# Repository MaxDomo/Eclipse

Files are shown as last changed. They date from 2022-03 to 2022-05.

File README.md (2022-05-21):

# Projet Eclipse

Bienvenue sur ce projet de motorisation de la lampe IKEA modèle PS2014

Vous pouvez retrouver l'ensemble de ce projet sur cet [article](https://www.domotioque-passion.fr/).

## Circuits et Schémas

Les circuits et schémas ont été conçus avec KiCad 6.0

## Pièces 3D

Les pièces ont été modélisées à l'aide de SolidWorks 2018.

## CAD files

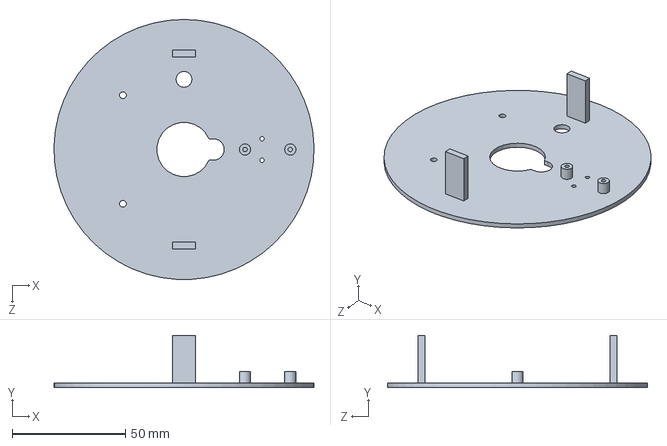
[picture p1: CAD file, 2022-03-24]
Pièces 3D/Support relais transformateur.SLDPRT
114.9 x 23.0 x 115.0 mm

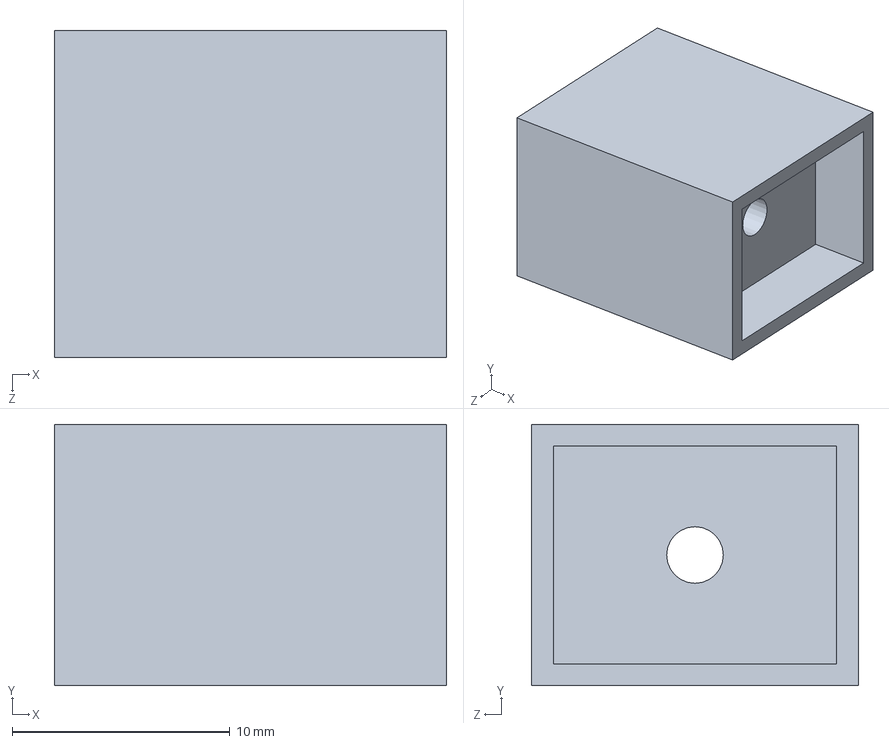
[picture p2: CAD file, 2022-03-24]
Pièces 3D/Support tendeur basV2.SLDPRT
18.0 x 12.0 x 15.0 mm

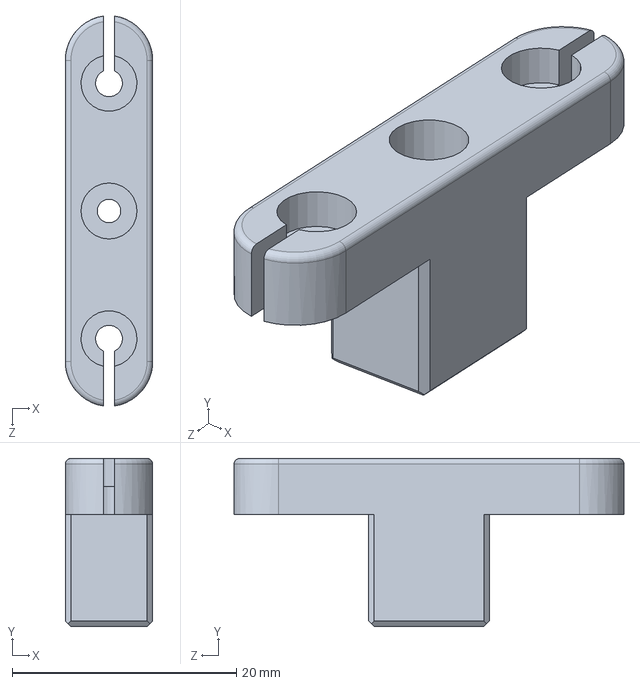
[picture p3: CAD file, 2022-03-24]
Pièces 3D/Tendeur basV2.SLDPRT
7.80 x 15.0 x 34.8 mm

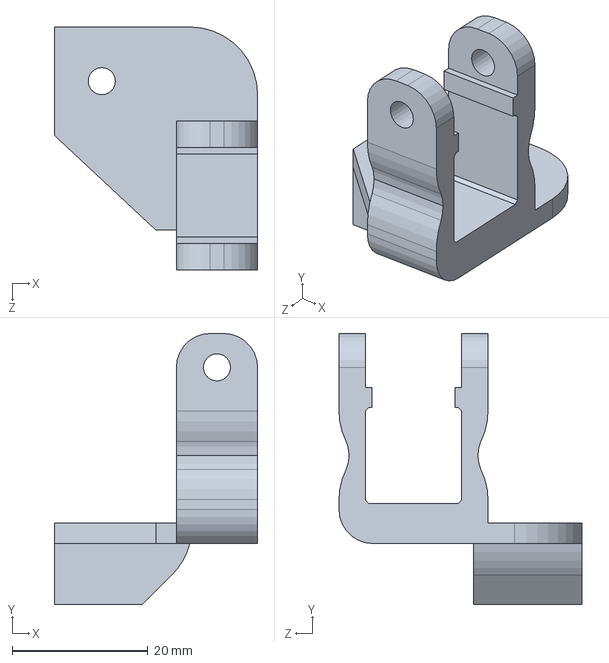
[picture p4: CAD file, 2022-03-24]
Pièces 3D/Support moteur.SLDPRT
30.0 x 40.0 x 35.9 mm

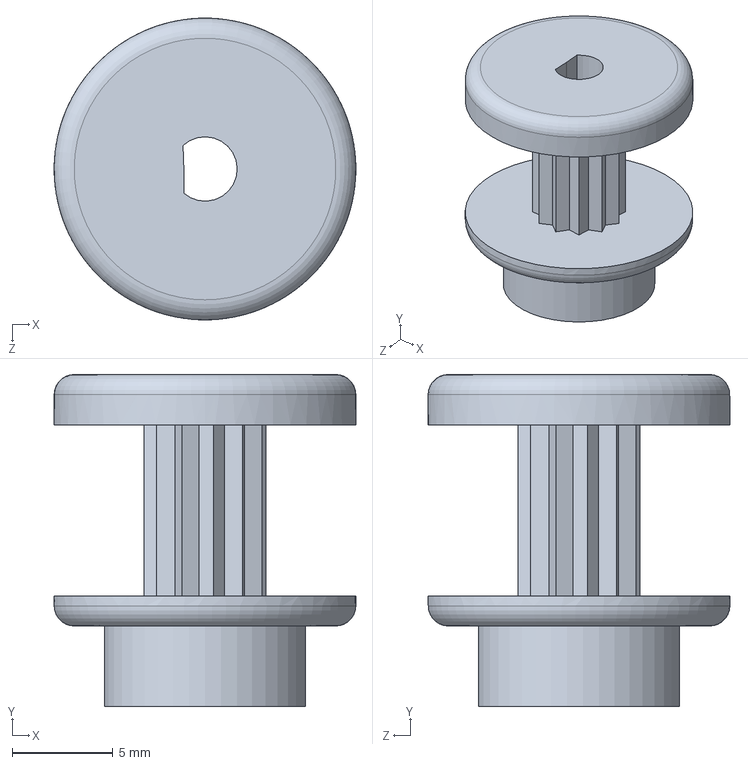
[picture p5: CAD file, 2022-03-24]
Pièces 3D/Roue tractionV2.SLDPRT
15.0 x 16.5 x 15.0 mm

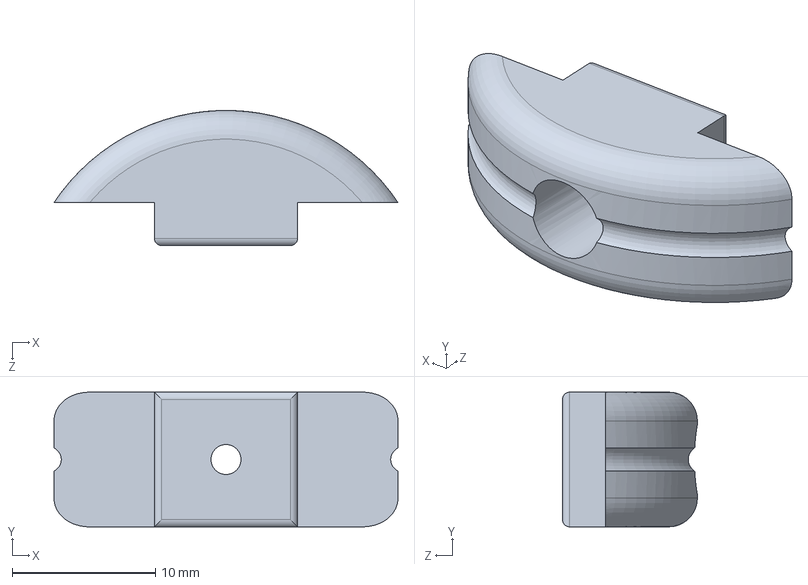
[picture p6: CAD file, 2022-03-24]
Pièces 3D/Tendeur hautV2.SLDPRT
24.0 x 9.40 x 9.42 mm

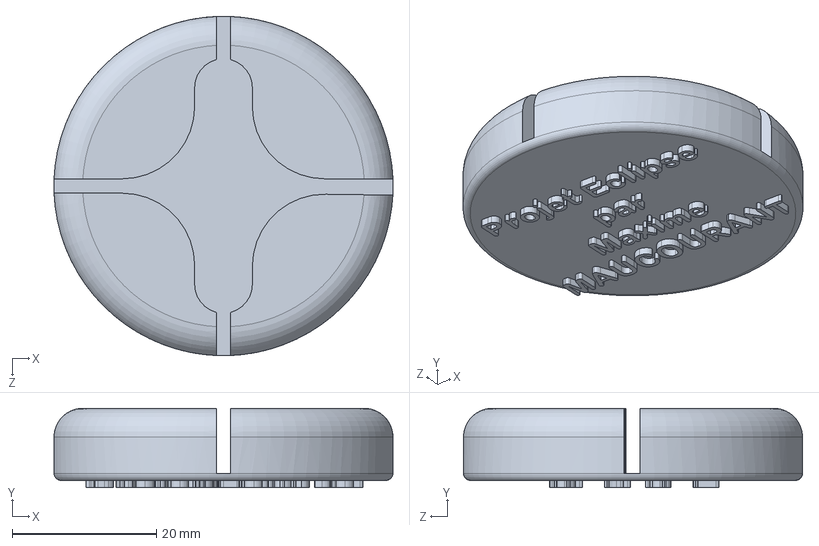
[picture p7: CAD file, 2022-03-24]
Pièces 3D/Estampille.SLDPRT
47.0 x 11.0 x 47.0 mm

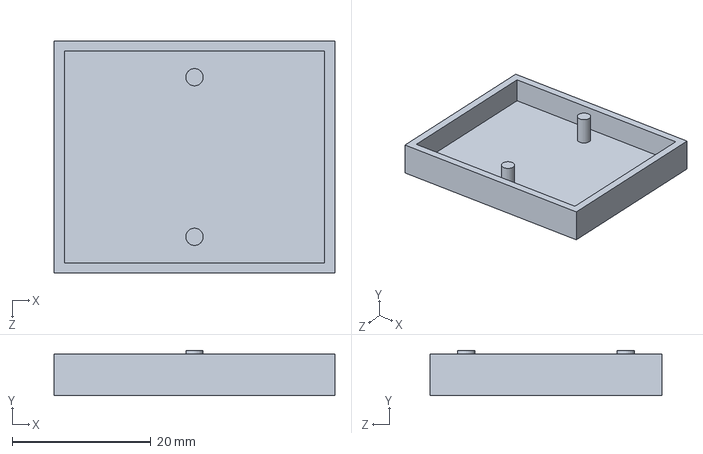
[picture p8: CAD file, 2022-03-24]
Pièces 3D/support carte relais.SLDPRT
40.5 x 6.50 x 33.5 mm

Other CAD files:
Pièces 3D/Roue traction.SLDPRT
Pièces 3D/Estampille.STL
Pièces 3D/Roue traction.STL
Pièces 3D/Roue tractionV2.STL
Pièces 3D/Support moteur.STL
Pièces 3D/Support relais transformateur.STL
Pièces 3D/Support tendeur basV2.STL
Pièces 3D/Tendeur basV2.STL
Pièces 3D/Tendeur hautV2.STL
Pièces 3D/support carte relais.STL

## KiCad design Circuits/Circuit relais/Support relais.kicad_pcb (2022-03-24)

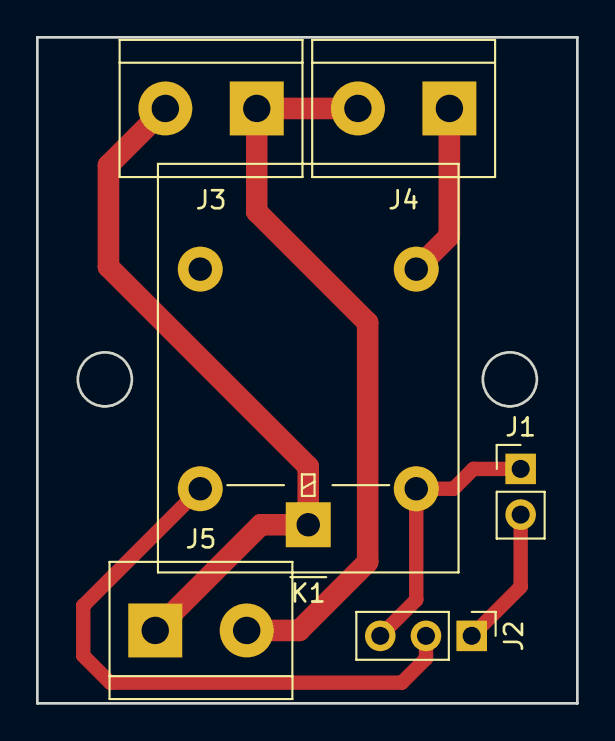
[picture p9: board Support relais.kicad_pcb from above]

Board: 2 copper layers, 30.0 x 37.0 mm, 6 parts (0 on the bottom side), 6 nets.

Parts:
J1: Conn_Power; PinHeader_1x02_P2.54mm_Vertical
J2: Conn_Power&Control; PinHeader_1x03_P2.54mm_Vertical
J3: AC Input; TerminalBlock_bornier-2_P5.08mm
J4: Light; TerminalBlock_bornier-2_P5.08mm
J5: Transformer; TerminalBlock_bornier-2_P5.08mm
K1: 5V; Relay_SPDT_Omron-G5LE-1

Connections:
unnamed: J1.1, J2.3, K1.2
unnamed: J1.2, J2.1
unnamed: J2.2, K1.5
unnamed: J4.1, K1.3
unnamed: J3.1, J4.2, J5.2
unnamed: J3.2, J5.1, K1.1

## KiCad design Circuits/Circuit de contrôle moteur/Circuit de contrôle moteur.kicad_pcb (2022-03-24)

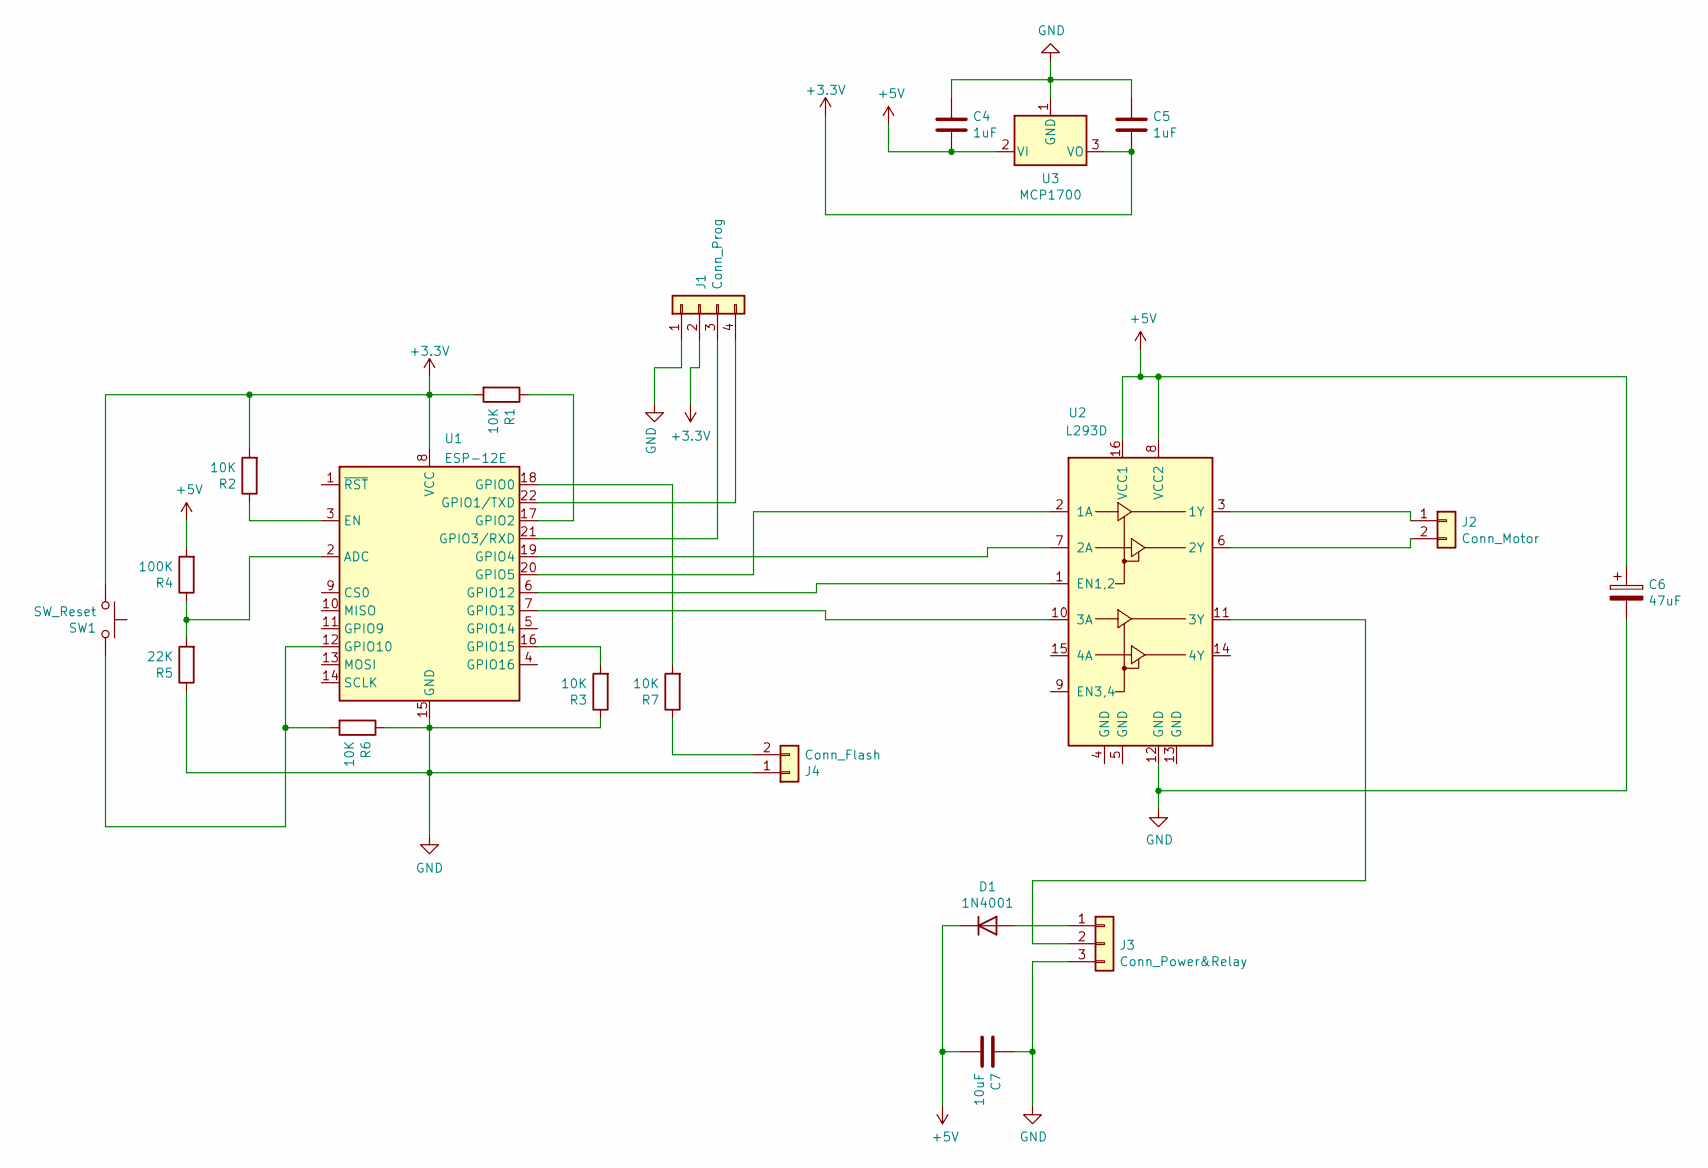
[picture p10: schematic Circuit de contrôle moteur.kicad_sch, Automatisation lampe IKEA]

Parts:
C4, C5: 1uF; C_Rect_L4.0mm_W2.5mm_P2.50mm
C6: 47uF; CP_Radial_D5.0mm_P2.50mm
C7: 10uF; C_Rect_L4.0mm_W2.5mm_P2.50mm
D1: 1N4001; D_DO-35_SOD27_P7.62mm_Horizontal
J1: Conn_Prog; PinHeader_1x04_P2.54mm_Vertical
J2: Conn_Motor; PinHeader_1x02_P2.54mm_Vertical
J3: Conn_Power&Relay; PinHeader_1x03_P2.54mm_Vertical
J4: Conn_Flash; PinHeader_1x02_P2.54mm_Vertical
R1, R2, R3, R6, R7: 10K; R_Axial_DIN0204_L3.6mm_D1.6mm_P7.62mm_Horizontal
R4: 100K; R_Axial_DIN0204_L3.6mm_D1.6mm_P7.62mm_Horizontal
R5: 22K; R_Axial_DIN0204_L3.6mm_D1.6mm_P7.62mm_Horizontal
SW1: SW_Reset; SW_PUSH_6mm_H4.3mm
U1: ESP-12E
U2: L293D; DIP-16_W7.62mm
U3: MCP1700; TO-92L_Wide

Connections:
+3V3: C5.2, J1.2, R1.2, R2.2, SW1.1, U1.8 (VCC), U3.3 (VO)
+5V: C4.2, C6.1, C7.2, D1.1 (K), R4.2, U2.8 (VCC2), U2.16 (VCC1), U3.2 (VI)
GND: C4.1, C5.1, C6.2, C7.1, J1.1, J3.3, J4.1, R3.1, R5.1, R6.1, U1.15 (GND), U2.12 (GND), U3.1 (GND)
unnamed: D1.2 (A), J3.1
unnamed: J1.3, U1.21 (GPIO3/RXD)
unnamed: J1.4, U1.22 (GPIO1/TXD)
unnamed: J2.1, U2.3 (1Y)
unnamed: J2.2, U2.6 (2Y)
unnamed: J3.2, U2.11 (3Y)
unnamed: J4.2, R7.1
unnamed: R1.1, U1.17 (GPIO2)
unnamed: R2.1, U1.3 (EN)
unnamed: R3.2, U1.16 (GPIO15)
unnamed: R4.1, R5.2, U1.2 (ADC)
unnamed: R7.2, U1.18 (GPIO0)
unnamed: U1.6 (GPIO12), U2.1 (EN1,2)
unnamed: U1.7 (GPIO13), U2.10 (3A)
unnamed: R6.2, SW1.2, U1.12 (GPIO10)
unnamed: U1.19 (GPIO4), U2.7 (2A)
unnamed: U1.20 (GPIO5), U2.2 (1A)

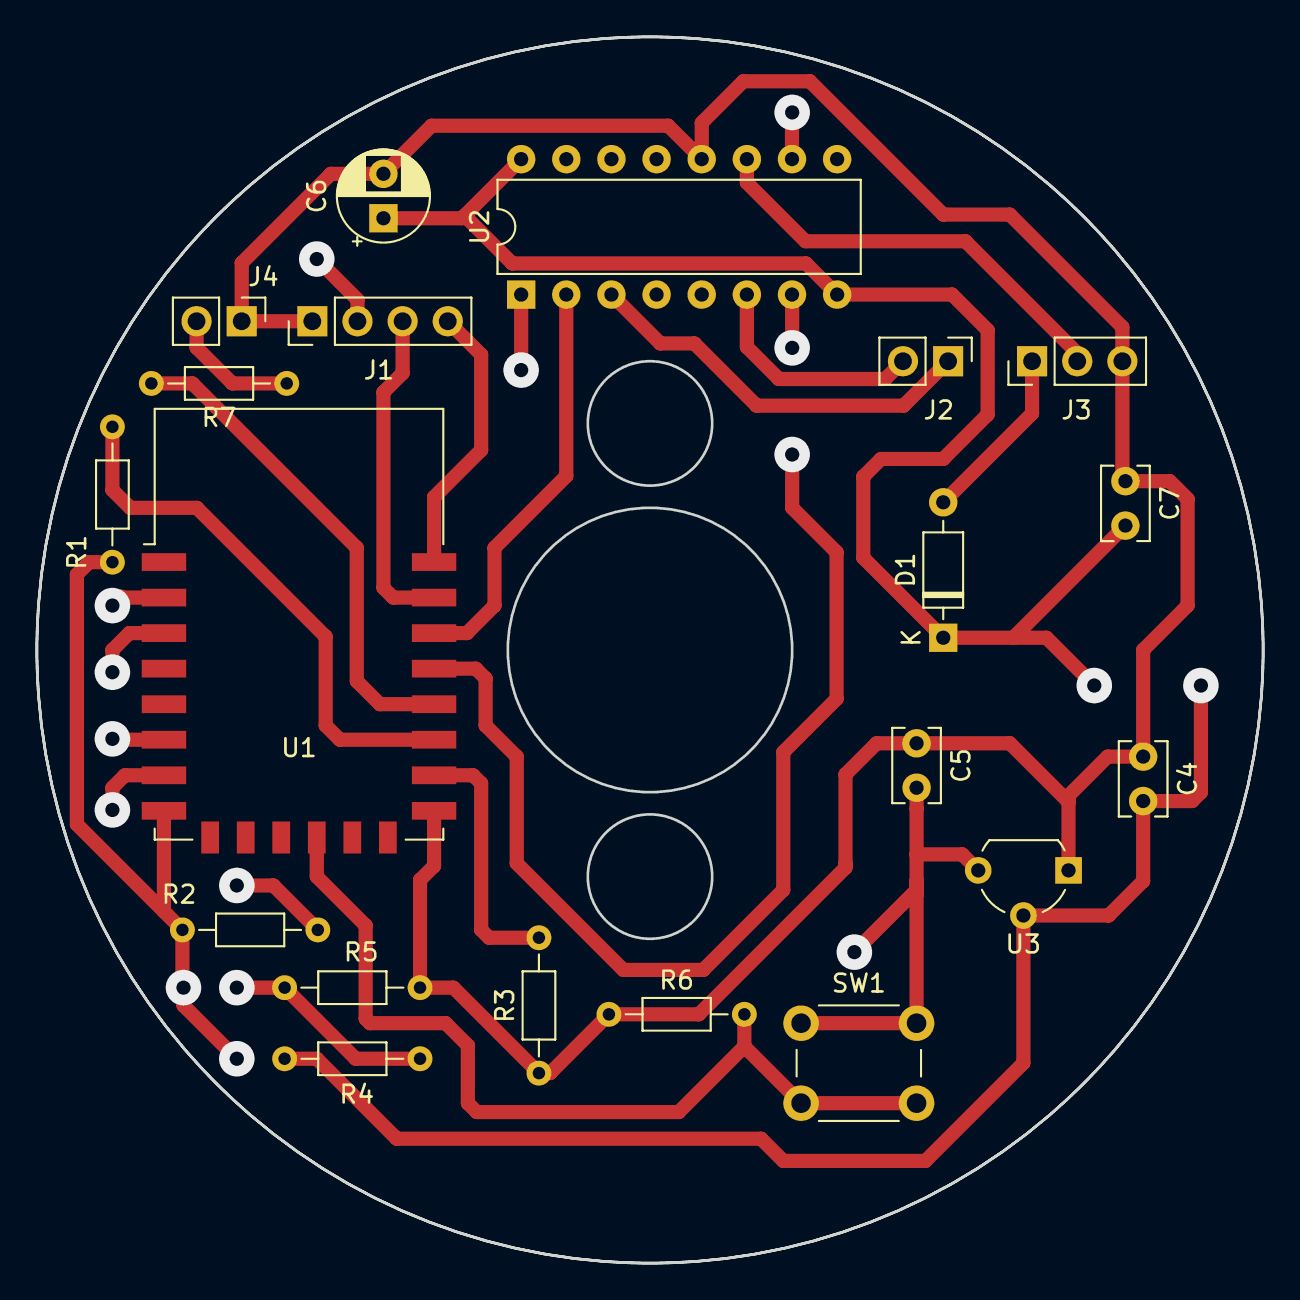
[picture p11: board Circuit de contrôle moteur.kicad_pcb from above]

Board: 2 copper layers, 69.0 x 69.0 mm, 20 parts (0 on the bottom side), 20 nets.

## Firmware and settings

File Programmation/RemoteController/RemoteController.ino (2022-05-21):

/////////////////////////////////
//       Projet ECLIPSE        //
// Ecrit par Maxime MAUCOURANT //
// MMAUCOURANT AT FREE DOT FR  //
/////////////////////////////////
#include <ESP8266WiFi.h>
#include <ESP8266HTTPClient.h>
#include <ESP8266WebServer.h>
#include <ESP8266mDNS.h>
#include "ESP8266httpUpdate.h"
#include <ArduinoJson.h>
#include <LittleFS.h>
#include "PubSubClient.h"
#include "EspAlexa.h"
#include "strings.h"

#define USEOTA
#ifdef USEOTA
#include <WiFiUdp.h>
#include <ArduinoOTA.h>
#endif

#define HTTP_OTA_URL "http://firmwares.domotique-passion.fr/eclipse/"
#define FIRMWARE_NAME "eclipse-v1.70-BETA"

#define FPSTR(pstr_pointer) (reinterpret_cast<const __FlashStringHelper *>(pstr_pointer))

#define pinSpeed 12
#define pinA 5
#define pinB 4

#define pinRelay 13 // Revoir l'affectation de la pin

#define pinSwitch 10

void lightDeviceChanged(EspalexaDevice *dev);
void lampShadeDeviceChanged(EspalexaDevice *dev);

// Déclaration du client Wifi
WiFiClient wifiClient;

// Déclaration du serveur web
ESP8266WebServer server(80);

// Déclaration du client MQTT
PubSubClient mqttClient(wifiClient);

DynamicJsonDocument config(1024);

Espalexa espalexa;
EspalexaDevice *lightDevice;
EspalexaDevice *lampShadeDevice;

int delayedPeriod = 1000;
unsigned long delayedTime;
void (*delayedFunction)();

// Init délai de tempo moteur
long motionDuration = 0;

// Init vitesse moteur
int motorSpeed = 100;

bool isRunning = false;
bool isClosed = false;

// Init délais d'ouverture/fermeture
int openingTime;
int closingTime;

// Init actions du moteur
int motorAction = -1;

// Init restauration états après coupure
bool restoreLastState = false;

// Variable pour la connexion à un nouveau réseau wifi
String newSSID;
String newPass;

// Etat de la dernière mise à jour
String lastUpdateStatus;

const char *hueLightName = "Eclipse light";
const char *hueLampshadeName = "Eclipse lampshade";

int mqttReconnectTime = 0;

int motorMotionTime = 0;

// Etat de la lumière
String lightStatus;

// Etat de l'abat jour
String lampshadeStatus;

int statusTime;

bool lastWifiConnected = false;

// Paramètre IP de station
IPAddress localIP(192, 168, 1, 1);
IPAddress gateway(192, 168, 1, 249);
IPAddress subnet(255, 255, 255, 0);

bool hueEnabled = false;
bool mqttEnabled = false;

void restart()
{
  if (WiFi.isConnected())
  {
    WiFi.disconnect();

    delay(1000);
  }

  ESP.restart();
}

IPAddress str2IP(String str)
{

  IPAddress ret(getIpBlock(0, str), getIpBlock(1, str), getIpBlock(2, str), getIpBlock(3, str));
  return ret;
}

int getIpBlock(int index, String str)
{
  char separator = '.';
  int found = 0;
  int strIndex[] = {0, -1};
  int maxIndex = str.length() - 1;

  for (int i = 0; i <= maxIndex && found <= index; i++)
  {
    if (str.charAt(i) == separator || i == maxIndex)
    {
      found++;
      strIndex[0] = strIndex[1] + 1;
      strIndex[1] = (i == maxIndex) ? i + 1 : i;
    }
  }

  return found > index ? str.substring(strIndex[0], strIndex[1]).toInt() : 0;
}

String JSONStringify(DynamicJsonDocument json)
{
  String buf;
  serializeJson(json, buf);
  return buf;
}

String getHostname()
{
  String macAddr = WiFi.macAddress();
  macAddr = macAddr.substring(10, macAddr.length());
  macAddr.replace(":", "");

  String hostname = "eclipse";
  hostname += "-";
  hostname += macAddr;

  return hostname;
}

// Fonction permettant d'obtenir la tension en milliVolt dans le circuit
unsigned int getVcc()
{
  // Calcul ADC
  // R1 = 100K
  // R2 = 22K
  // Vout = Vin * R2 / (R1 + R2)
  // 5 * 22 / (100 + 22) = 0.9016393443
  // Ratio pont diviseur = 5 / 0.9016393443 = 5.54
  // LSB = (0.901639 / 1017) * 5.54 = 0.004911583

  float LSB = 0.004911583;
  int ADC = analogRead(A0);

  return (ADC * LSB) * 1000; // mV
}

void lightBlink(int count = 1, int wait = 500)
{
  // Eteint la lumière
  digitalWrite(pinRelay, LOW);

  // On fait clignoter 3 fois la lumière
  for (int i = 0; i < count; i++)
  {
    delay(wait);
    digitalWrite(pinRelay, HIGH);
    delay(wait);
    digitalWrite(pinRelay, LOW);
  }
}

// Fonction pour construire le topic MQTT
String mqttTopicBuilder(String prefix, String topic)
{
  String fullTopic = config["mqtt"]["full_topic"].as<String>();
  fullTopic.replace("{prefix}", prefix);
  fullTopic.replace("{topic}", config["mqtt"]["topic"].as<String>());
  fullTopic += "/" + topic;

  return fullTopic;
}

// Fonction permettant de publier des messages sur un topic MQTT
void mqttPublish(String prefix, String topic, String payload, bool retain = false)
{
  String fullTopic = mqttTopicBuilder(prefix, topic);

  mqttClient.publish(fullTopic.c_str(), payload.c_str(), retain);
}

// Fonction de connexion au serveur MQTT
void mqttConnect(String client, String user, String pass, String inTopic)
{
  if (pass == "")
  {
    mqttClient.connect(client.c_str());
  }
  else
  {
    mqttClient.connect(client.c_str(), user.c_str(), pass.c_str());
  }

  // Construction des topic lampe et abat jour
  String lightTopic = mqttTopicBuilder("cmnd", "LIGHT");
  String lampshadeTopic = mqttTopicBuilder("cmnd", "LAMPSHADE");

  // Souscription aux topics pour les receptions de messages
  mqttClient.subscribe(lightTopic.c_str());
  mqttClient.subscribe(lampshadeTopic.c_str());
}

void mqttCallback(char *topic, byte *payload, unsigned int length)
{
  String topicStr = topic;
  payload[length] = 0;
  String cmd = String((char *)payload);

  cmd.toLowerCase();

  if (topicStr == mqttTopicBuilder("cmnd", "LIGHT") || topicStr == mqttTopicBuilder("cmnd", "LAMPSHADE"))
  {
    sendCommand(cmd);
  }
}

#ifdef USEOTA
// Fonction permettant d'activer les mises à jour à travers le WiFi (OTA - Over The Air)
void beginOTA(const char *hostname)
{
  ArduinoOTA.setHostname(hostname);
  ArduinoOTA.begin();
}
#endif

// Fonction de chargement du fichier de configuration JSON
void loadConfig()
{
  if (LittleFS.begin())
  {
    if (LittleFS.exists("/config.json"))
    {
      File configFile = LittleFS.open("/config.json", "r");
      if (configFile)
      {
        deserializeJson(config, configFile);

        configFile.close();
      }
    }
  }
}

// Fonction de sauvegarde de configuration dans un fichier JSON
void saveConfig()
{
  File configFile = LittleFS.open("/config.json", "w");
  if (configFile)
  {
    serializeJson(config, configFile);

    configFile.close();
  }
}

// Fonction de réinitialisation de l'ESP
void reset()
{
  if (LittleFS.exists("/config.json"))
  {
    LittleFS.remove("/config.json");
  }

  WiFi.disconnect();
  startSoftAP(getHostname());
  config.clear();
}

// Fonction appelée en cas de page non trouvée (404)
void handleNotFound()
{
  if (hueEnabled && espalexa.handleAlexaApiCall(server.uri(), server.arg(0)))
  {
  }
  else
  {
    server.send(404, "text/plain", "Not found");
  }
}

// Fonction appelée pour le chargement d'un script
void handleJSLib()
{
  server.send(200, "text/plain", FPSTR(JS_lib));
}

// Fonction pour générer la page de config système
void handleConfig()
{
  String page;

  // Construction des éléments du DOM
  page += FPSTR(HTTP_HEAD_START);
  page += FPSTR(HTTP_STYLE);
  page += FPSTR(HTTP_SCRIPT);
  page += FPSTR(HTTP_HEAD_END);
  page += FPSTR(CONFIG_PAGE);
  page += FPSTR(HTTP_END);

  page.replace("{title}", "Configuration");

  server.send(200, "text/html", page);
}

// Fonction pour générer la page principal
void handleRoot()
{
  String page;

  // Construction des éléments du DOM
  page += FPSTR(HTTP_HEAD_START);
  page.replace("{title}", "Main");
  page += "<script src='script.js'></script>";
  page += FPSTR(HTTP_STYLE);
  page += FPSTR(HTTP_HEAD_END);
  page += FPSTR(MAIN_PAGE);
  page += FPSTR(HTTP_END);

  server.send(200, "text/html", page);
}

// Fonction permettant de générer la page de mise à jour du firmware
void handleUpdate()
{
  String page;

  // Construction des éléments du DOM
  page += FPSTR(HTTP_HEAD_START);
  page += FPSTR(HTTP_REFRESH);
  page += FPSTR(HTTP_STYLE);
  page += FPSTR(HTTP_HEAD_END);

  page.replace("{title}", "Firmware Update");

  if (!server.hasArg("finished"))
  {
    page += FPSTR(HTTP_UPDATE_START);

    page.replace("{time}", "30");
    page.replace("{url}", "/update?finished");

    // Lancement de la méthode de vérification d'une mise à jour en mode asynchrone
    delayedPeriod = 2000;
    delayedTime = millis();
    delayedFunction = &checkOTAUpdate;
  }
  else
  {
    page += FPSTR(HTTP_UPDATE_RESULT);

    if (lastUpdateStatus == "")
    {
      lastUpdateStatus = "Update successful";
    }

    page.replace("{updateStatus}", lastUpdateStatus);
    page.replace("{time}", "10");
    page.replace("{url}", "/");
  }

  page += FPSTR(HTTP_END);

  server.send(200, "text/html", page);
}

// Fonction permettant de générer la page de config système
void handleSystem()
{
  String page;

  // Construction des éléments du DOM
  page += FPSTR(HTTP_HEAD_START);
  page += FPSTR(HTTP_STYLE);
  page += FPSTR(HTTP_SCRIPT);
  page += FPSTR(HTTP_HEAD_END);
  page += FPSTR(SYSTEM_PAGE);
  page += FPSTR(HTTP_END);

  // Remplacement des valeurs
  page.replace("{title}", "System Configuration");
  page.replace("{opentime}", (String)(config["open_time"].as<int>() | 0));
  page.replace("{closetime}", (String)(config["close_time"].as<int>() | 0));
  page.replace("{currentvoltage}", (String)getVcc());
  page.replace("{maxdropvoltage}", (String)(config["maxdropvoltage"].as<int>() | 150));
  page.replace("{maxdetectiontime}", (String)(config["maxdetectiontime"].as<int>() | 30));
  page.replace("{synclight}", (config["sync_light"] ? "checked" : ""));

  server.send(200, "text/html", page);
}

// Fonction appelée lors de la sauvegarde de la config système
void handleSystemSave()
{
  String page;

  // Construction des éléments du DOM
  page += FPSTR(HTTP_HEAD_START);
  page += FPSTR(HTTP_REFRESH);
  page += FPSTR(HTTP_STYLE);
  page += FPSTR(HTTP_HEAD_END);

  page.replace("{title}", "System Configuration");

  // Récupération des paramètres POST
  bool syncLight = server.hasArg("synclight");
  int openTime = server.arg("opentime").toInt();
  int closeTime = server.arg("closetime").toInt();
  int maxDropVoltage = server.arg("maxdropvoltage").toInt();
  int maxDetectionTime = server.arg("maxdetectiontime").toInt();

  if (openTime <= 0 || openTime > 30)
  {
    page += FPSTR("Closing time must be between 0 and 30 seconds");
  }
  else if (closeTime <= 0 || closeTime > 30)
  {
    page += FPSTR("Opening time must between 0 and 30 secondes");
  }
  else if (maxDropVoltage <= 0 || maxDropVoltage > 600)
  {
    page += FPSTR("Maximum drop voltage must between 0 and 600 secondes");
  }
  else if (maxDetectionTime <= 0 || maxDetectionTime > 50)
  {
    page += FPSTR("Maximum detection time must between 0 and 50 secondes");
  }
  else
  {
    page += FPSTR(HTTP_SYSTEM_SUCCESS);

    // Sauvegarde des paramètres
    config["sync_light"] = syncLight;
    config["open_time"] = openTime;
    config["close_time"] = closeTime;
    config["max_drop_voltage"] = maxDropVoltage;
    config["max_detection_time"] = maxDetectionTime;

    openingTime = openTime;
    closingTime = closeTime;

    saveConfig();
  }

  page += FPSTR(HTTP_END);

  page.replace("{time}", "5");
  page.replace("{url}", "/system");

  server.send(200, "text/html", page);
}

// Fonction permettant de générer la page de configuration MQTT
void handleMQTT()
{
  String page;

  // Récupération de nom d'hôte
  String hostname = getHostname();

  hostname.replace('-', '_');
  hostname.toUpperCase();

  // Construction des éléments du DOM
  page += FPSTR(HTTP_HEAD_START);
  page += FPSTR(HTTP_STYLE);
  page += FPSTR(HTTP_HEAD_END);
  page += FPSTR(MQTT_PAGE);
  page += FPSTR(HTTP_END);

  // Remplacement des valeurs avec des présentes la configuration
  page.replace("{title}", "MQTT Configuration");
  page.replace("{checked}", (config["mqtt"]["enabled"] ? "checked" : ""));
  page.replace("{host}", config["mqtt"]["host"] | "");
  page.replace("{port}", config["mqtt"]["port"] | "1883");
  page.replace("{port}", config["mqtt"]["port"] | "1883");
  page.replace("{client}", config["mqtt"]["client"] | "eclipse");
  page.replace("{user}", config["mqtt"]["user"] | "");
  page.replace("{pass}", config["mqtt"]["pass"] | "");
  page.replace("{topic}", config["mqtt"]["topic"] | hostname);
  page.replace("{fulltopic}", config["mqtt"]["full_topic"] | "{prefix}/{topic}");

  server.send(200, "text/html", page);
}

// Fontion appelée lors de la sauvegarde de la page de config MQTT
void handleMQTTSave()
{
  String page;

  // Construction des éléments du DOM
  page += FPSTR(HTTP_HEAD_START);
  page.replace("{title}", "MQTT Configuration saved");
  page += FPSTR(HTTP_REFRESH);
  page += FPSTR(HTTP_STYLE);
  page += FPSTR(HTTP_HEAD_END);

  // Récupération des paramètres (POST)
  mqttEnabled = server.hasArg("enable");

  String host = server.arg("host");
  String port = server.arg("port");
  String clientName = server.arg("client");
  String user = server.arg("user");
  String pass = server.arg("pass");
  String topic = server.arg("topic");
  String fullTopic = server.arg("fulltopic");

  if (mqttEnabled && (host == "" || port == ""))
  {
    page += FPSTR("MQTT host or port cannot be empty");
    page.replace("{time}", "5");
  }
  else if (mqttEnabled && user == "")
  {
    page += FPSTR("MQTT user cannot be empty");
    page.replace("{time}", "5");
  }
  else if (mqttEnabled && (topic == "" || fullTopic == ""))
  {
    page += FPSTR("MQTT topic or fullTopic cannot be empty");
    page.replace("{time}", "5");
  }
  else
  {
    page += FPSTR(HTTP_MQTT_SUCCESS);

    // Sauvegarde des paramètres
    config["mqtt"]["enabled"] = mqttEnabled;
    config["mqtt"]["host"] = host;
    config["mqtt"]["port"] = port;
    config["mqtt"]["client"] = clientName;
    config["mqtt"]["user"] = user;
    config["mqtt"]["pass"] = pass;
    config["mqtt"]["topic"] = topic;
    config["mqtt"]["full_topic"] = fullTopic;

    saveConfig();

    page.replace("{time}", "30");

    // Rédemarrage de l'ESP
    delayedPeriod = 5000;
    delayedTime = millis();
    delayedFunction = &restart;
  }

  page += FPSTR(HTTP_END);

  page.replace("{url}", "/mqtt");

  server.send(200, "text/html", page);
}

// Fontion appelée pour construire la page de configuration HUE
void handleHUE()
{
  String page;

  // Construction des éléments du DOM
  page += FPSTR(HTTP_HEAD_START);
  page += FPSTR(HTTP_STYLE);
  page += FPSTR(HTTP_HEAD_END);
  page += FPSTR(HUE_PAGE);
  page += FPSTR(HTTP_END);

  // Remplacement des valeurs
  page.replace("{title}", "HUE Emulator Configuration");
  page.replace("{checked}", (config["hue"]["enabled"] ? "checked" : ""));
  page.replace("{lightname}", config["hue"]["light_name"] | hueLightName);
  page.replace("{lampshadename}", config["hue"]["lampshade_name"] | hueLampshadeName);

  server.send(200, "text/html", page);
}

// Fontion appelée lors de la sauvegarde des paramètres HUE
void handleHUESave()
{
  String page;

  // Construction des éléments du DOM
  page += FPSTR(HTTP_HEAD_START);
  page += FPSTR(HTTP_REFRESH);
  page += FPSTR(HTTP_STYLE);
  page += FPSTR(HTTP_HEAD_END);

  page.replace("{title}", "HUE Emulation Configuration saved");

  hueEnabled = server.hasArg("enable");

  String lightName = server.arg("light-name");
  String lampshadeName = server.arg("lampshade-name");

  if (hueEnabled && (lightName == "" || lampshadeName == ""))
  {
    page += FPSTR("Light or lampshade name cannot be empty !");
    page.replace("{time}", "5");
  }
  else
  {
    page += FPSTR(HTTP_HUE_SUCCESS);

    // Sauvegarde des paramètres
    config["hue"]["enabled"] = hueEnabled;
    config["hue"]["lignt_name"] = lightName;
    config["hue"]["lampshade_name"] = lampshadeName;

    saveConfig();

    // Redémarrage de l'ESP
    delayedPeriod = 5000;
    delayedTime = millis();
    delayedFunction = &restart;
  }

  page += FPSTR(HTTP_END);

  page.replace("{url}", "/hue");

  server.send(200, "text/html", page);
}

// Fonction appelée pour la construction de la page de séléction des réseaux WiFi
void handleWifi()
{
  String page;

  // Construction des éléments du DOM
  page += FPSTR(HTTP_HEAD_START);
  page += FPSTR(HTTP_STYLE);
  page += FPSTR(HTTP_SCRIPT);
  page += FPSTR(HTTP_HEAD_END);
  page += getNetworks();

  page += FPSTR(HTTP_END);

  page.replace("{title}", "Wifi Network");

  server.send(200, "text/html", page);
}

// Fontion appelée lors de la sauvegarde des paramètres WiFi
void handleWifiSave()
{
  String ssid = server.arg("ssid");
  String pass = server.arg("password");

  String page;

  // Construction des éléments du DOM
  page += FPSTR(HTTP_HEAD_START);
  page += FPSTR(HTTP_REFRESH);
  page += FPSTR(HTTP_STYLE);
  page += FPSTR(HTTP_HEAD_END);

  page.replace("{title}", "Wifi");

  if (server.hasArg("ip"))
  {
    if (server.hasArg("static"))
    {
      config["wifi"]["static"] = true;
      config["wifi"]["ip"] = (server.arg("ip") != "") ? server.arg("ip") : WiFi.localIP().toString();
      config["wifi"]["subnet"] = (server.arg("subnet") != "") ? server.arg("subnet") : WiFi.subnetMask().toString();
      config["wifi"]["gateway"] = (server.arg("gateway") != "") ? server.arg("gateway") : WiFi.gatewayIP().toString();
      config["wifi"]["dns"] = (server.arg("dns") != "") ? server.arg("dns") : WiFi.dnsIP().toString();

      String url = "http://";
      url += config["wifi"]["ip"].as<String>();
      url += "/";

      page.replace("{url}", url);
    }
    else
    {
      config["wifi"]["static"] = false;
      config["wifi"]["ip"] = "";
      config["wifi"]["subnet"] = "";
      config["wifi"]["gateway"] = "";
      config["wifi"]["dns"] = "";

      String url = "http://";
      url += getHostname();
      url += ".local/";

      page.replace("{url}", url);
    }

    saveConfig();

    delayedPeriod = 10000;
    delayedTime = millis();
    delayedFunction = &restart;

    page += FPSTR(HTTP_WIFI_PARAMS_SUCCESS);
    page.replace("{time}", "30");
  }

  if (server.hasArg("ssid"))
  {
    if (lastWifiConnected)
    {
      page += FPSTR(HTTP_WIFI_CONNECT);
      page.replace("{ssid}", ssid);

      newSSID = ssid;
      newPass = pass;

      delayedPeriod = 5000;
      delayedTime = millis();
      delayedFunction = &connectNewWifi;
    }
    else
    {
      if (wifiConnect(ssid, pass))
      {
        config["wifi"]["ssid"] = ssid;
        config["wifi"]["pass"] = pass;

        // Sauvegarde des identifiants
        saveConfig();

        String newUrl = "http://";
        newUrl += WiFi.localIP().toString();
        newUrl += "/";

        page += FPSTR(HTTP_WIFI_CONNECT_SUCCESS);

        page.replace("{time}", "30");
        page.replace("{url}", newUrl);

        // Redémarrage de l'ESP
        delayedPeriod = 10000;
        delayedTime = millis();
        delayedFunction = &restart;
      }
      else
      {

        String url = "http://";
        url += WiFi.softAPIP().toString();
        url += "/wifi";

        page += FPSTR(HTTP_WIFI_CONNECT_FAIL);

        page.replace("{time}", "30");
        page.replace("{url}", url);
      }
    }
  }

  page += FPSTR(HTTP_END);

  server.send(200, "text/html", page);
}

// Fonction de récupération des commandes HTTP
void handleCommand()
{
  DynamicJsonDocument result(512);

  // Commande de la lampe et abat jour
  if (server.hasArg("light"))
  {
    sendCommand(server.arg("light"));
    result["success"] = true;
    server.send(200, "application/json", JSONStringify(result));
  }
  else if (server.arg("restore") == "on")
  {
    restoreLastState = true;
    config["restore_state"] = restoreLastState;
    saveConfig();
    result["success"] = true;
    server.send(200, "application/json", JSONStringify(result));
  }
  else if (server.arg("restore") == "off")
  {
    restoreLastState = false;
    config["restore_state"] = restoreLastState;
    saveConfig();
    result["success"] = true;
    server.send(200, "application/json", JSONStringify(result));
  }
  else if (server.hasArg("status"))
  {
    result["status"]["light"] = lightStatus;
    result["status"]["lampshade"] = lampshadeStatus;
    result["success"] = true;

    server.send(200, "application/json", JSONStringify(result));
  }
  // Commande de lancement de mode d'apprentissage
  else if (server.hasArg("learning"))
  {
    sendCommand("learn");
    result["success"] = true;
    server.send(200, "application/json", JSONStringify(result));
  }
  // Commande de réinitialisation
  else if (server.hasArg("reset"))
  {
    result["success"] = true;
    server.send(200, "application/json", JSONStringify(result));

    delayedPeriod = 2000;
    delayedTime = millis();
    delayedFunction = &reset;
  }
  else
  {
    result["success"] = false;
    result["message"] = "Unknown command";
    server.send(401, "application/json", JSONStringify(result));
  }
}
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
void loop()
{
#ifdef USEOTA
  ArduinoOTA.handle();
#endif

  MDNS.update();

  if (digitalRead(pinSwitch) == HIGH)
  {
    motorAction = 0;
    motionDuration = 10000;
  }

  server.handleClient();

  checkDelayed();

  checkStatus();

  // Vérification des ordres moteur
  checkMotor();

  if (WiFi.isConnected())
  {
    if (mqttEnabled)
    {
      mqttClient.loop();
    }

    if (hueEnabled)
    {
      espalexa.loop();
    }
  }
}

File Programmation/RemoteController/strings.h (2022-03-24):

const char MAIN_PAGE[] PROGMEM = R"=====(
    <div style='text-align:left;display:inline-block;color:#000;min-width:340px;'>
      <noscript>To use this interface, please enable JavaScript <br></noscript>
      <table style="width:100%">
        <tbody>
          <tr>
            <td id="light-status" style="width:100%;text-align:center;font-weight:bold;font-size:60px">-</td>
          </tr>
          <tr>
            <td id="lampshade-status" style="width:100%;text-align:center;font-weight:bold;font-size:40px">-</td>
          </tr>
        </tbody>
      </table>
      <div style="display: block;"></div>
      <p>
        <button type="button" onclick="xhr.abort(); fetch('cmd?light=toggle');">ON / OFF</button>
      </p>
      <p>
        <button type="button" id="lampshade-action" data-action="open" onclick="xhr.abort(); var btnLampshade = document.getElementById('lampshade-action'); btnLampshade.setAttribute('disabled', 'disabled'); fetch('cmd?light=' + btnLampshade.getAttribute('data-action'));">Open</button>
      </p>
      <p>
        <form style="display: block;" action="infos"><button type="submit">Informations</button></form>
      </p>
      <p>
        <form style="display: block;" action="config"><button type="submit">Configuration</button></form>
      </p>
    </div>
)=====";

const char INFOS_PAGE[] PROGMEM = R"=====(
<table style="width:100%">
   <tbody>
      <tr>
         <th>Firmware version</th>
         <td>{firmware}</td>
      </tr>
      <tr>
         <th>Hostname</th>
         <td>{host}</td>
      </tr>
      <tr>
         <th>Uptime</th>
         <td>{uptime_mins} min(s) {uptime_secs} second(s)</td>
      </tr>
      <tr>
         <th>Restart Reason</th>
         <td>{restartreason}</td>
      </tr>  
      <tr>
         <th>Circuit Voltage</th>
         <td>{vcc} mV</td>
      </tr>
      <tr>
         <th>Lampshade opening time</th>
         <td>{opentime} seconds</td>
      </tr> 
      <tr>
         <th>Lampshade closing time</th>
         <td>{closetime} seconds</td>
      </tr>              
      <tr>
         <th></th>
         <td>&nbsp;</td>
      </tr>
      <tr>
         <th>SSID</th>
         <td>{ssid}</td>
      </tr>
      <tr>
         <th>MAC Address</th>
         <td>{mac}</td>
      </tr>
      <tr>
         <th>IP Address</th>
         <td>{ip}</td>
      </tr>
      <tr>
         <th>Gateway</th>
         <td>{gw}</td>
      </tr>
      <tr>
         <th>Subnet Mask</th>
         <td>{mask}</td>
      </tr>
      <tr>
         <th>DNS Server</th>
         <td>{dns}</td>
      </tr>
      <tr>
         <th>Wifi connected</th>
         <td>{isconnected}</td>
      </tr>
      <tr>
         <th>Auto reconnection</th>
         <td>{autocon}</td>
      </tr>      
      <tr>
         <th></th>
         <td>&nbsp;</td>
      </tr>
      <tr>
         <th>MQTT</th>
         <td>{mqttenable}</td>
      </tr>
      <tr>
         <th>HUE Emulator</th>
         <td>{hueenable}</td>
      </tr>
      <tr>
         <th></th>
         <td>&nbsp;</td>
      </tr>
      <tr>
         <th>ESP Chip Id</th>
         <td>{fchipid}</td>
      </tr>
      <tr>
         <th>Core / SDK Version</th>
         <td>{corever} / {sdkver}</td>
      </tr>
      <tr>
         <th>Boot Version</th>
         <td>{bootver}</td>
      </tr>
      <tr>
         <th>CPU Frequency</th>
         <td>{cpufreq}</td>
      </tr>      
      <tr>
         <th>Real Flash Size</th>
         <td>{flashsize} bytes</td>
      </tr>
      <tr>
         <th>Flash Size</th>
         <td>{idesize} bytes</td>
      </tr>        
      <tr>
         <th>Memory</th>
         <td><progress value='{memsmeter_current}' max='{memsmeter_max}'></progress></td>
      </tr>
      <tr>
         <th>Memory Sketch Size</th>
         <td>{memsketch_current} / {memsketch_max}</td>
      </tr> 
      <tr>
         <th>Memory Free Heap</th>
         <td>{freeheap} bytes available</td>
      </tr>               
   </tbody>
</table>
<br/>
<form action="/">
  <button type="submit">Back</button></form>
</form>
)=====";

const char CONFIG_PAGE[] PROGMEM = R"=====(
<div style='text-align:left;display:inline-block;color:#000;min-width:340px;'>
  <p>
    <form style="display: block;" action="/system"><button type="submit">System</button></form>
  </p>
  <p>
    <form style="display: block;" action="/hue"><button type="submit">HUE Emulator</button></form>
  </p>
  <p>
    <form style="display: block;" action="/mqtt"><button type="submit">MQTT</button></form>
  </p>
  <p>
    <form style="display: block;" action="/wifi"><button type="submit">Network</button></form>
  </p>
  <p>
    <form action="/">
      <button type="submit">Back</button>
    </form>
  </p>
</div>
)=====";

const char HTTP_FORM_WIFI[] PROGMEM = R"=====(
<p><button type='button' onclick='window.location.reload();'>Refresh</button></p>
<br/>  
<fieldset>
  <legend><b>{title}</b></legend>
  <form action='/wifisave' method='POST'>
    <p><b><label for='ssid'>SSID</label><input id='ssid' name='ssid' maxlength='32' autocorrect='off' autocapitalize='none' value='{ssid}'></b></p>
    <p><b><label for='password'>Password</label><input id='password' name='password' maxlength='64' type='text' value='{password}'></b></p>
    <p><button type="submit" name="save-ssid" value="on" class='danger'>Save</button></p>
  </form>
</fieldset>  
)=====";

const char HTTP_FORM_WIFI_PARAMS[] PROGMEM = R"=====(
<br/>
<fieldset>
   <legend><b>Custom parameters</b></legend>
   <form method="POST" action="/wifisave">
      <p><label><input style="width:50px;" type="checkbox" {checked} name="static"><b>Enable static</b></label></p>
      <p><b>IP address</b><br><input placeholder="{pip}" value="{ip}" name="ip"></p>
      <p><b>Subnet</b><br><input placeholder="{psubnet}" value="{subnet}" name="subnet"></p>
      <p><b>Gateway</b><br><input placeholder="{pgateway}" value="{gateway}" name="gateway"></p>
      <p><b>DNS</b><br><input placeholder="{pdns}" value="{dns}" name="dns"></p>
      <br><button name="save-network" type="submit">Save</button>
   </form>
</fieldset>
)=====";

const char HTTP_FORM_WIFI_BACK[] PROGMEM = R"=====(
<p>
  <form action="/config">
    <button type="submit">Back</button>
  </form>
</p>  
)=====";
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
